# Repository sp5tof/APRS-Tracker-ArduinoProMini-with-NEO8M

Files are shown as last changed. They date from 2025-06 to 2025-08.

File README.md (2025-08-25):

# APRS Tracker/Decoder for Baofeng based on ArduinoProMini, ESP32 & NEO8M GPS receiver module
This project is based on:

- Billy's project : https://github.com/billygr/arduino-aprs-tracker  - more informations: https://www.billy.gr/arduino-aprs-tracker/ &
- ESP32 iGate project https://github.com/nakhonthai/ESP32APRS_Audio

It consists of two independent uC: Arduino Pro-Mini for TNC transmition and ESP-Wroom32 with OLED board for visual decoding incoming APRS frames.
This is becouse I wasn't able to force Atmega328p with Arduino bootloader to decode any AX.25 frames using the another decoder idea :
https://github.com/chokelive/aprs_tnc .
From the other hand, ESP32 iGate standalone project doesn't seem to support the NEO8M GPS receiver. 
That's why I decided to use hybrid solution consists of two independent microprocessors.

Attached Eagle STL/BRD PCB allows to put them all together.

Baofeng is used as transceiver for this project and connected with two embedded mini-jacks sockets for TX/RX datas & PTT triggering.

I changed few things related to genuine project(Arduino Pro-Mini part):
- support for NEO8M GPS module (TinyGPS library has to be changed, I added the modified library here)
- small change made on original Billy's arduino code related to GPS module
- I used Arduino Pro mini in 5V version and adopted author's code to use this one
- added additional button for changing the APRS symbol(pressing it during the powering ON the device would change the symbol from "car" to "walking man")

I added external speaker with embedded preamp to the circuit as you can see on the schema. Baofeng turns off it's internal speaker when the mini-jack is plugged in. The idea behind the external speaker is about possibility of listening incoming APRS frames. Unfortunatelly, two audio receivers on the DAC output of esp32 makes overriding the audio line. That's why I had to add the audio splitter based on TL072.
  
Cable required for connecting the Baofeng with the device you have to make on your own. I wasn't able to find fully compatible 4-pins (MIC, SPK, PTT, GND) cable with any well-known online stores. However, you can try to order the baofeng audio cable from chinese online store, but the additional changes will have to be made according the the attached schema and pinout available in the net, f. ex : https://www.miklor.com/COM/images/dualplug.jpg .

For Arduino part, please compile and upload attached .ino code to the Arduino Pro-Mini.
Make necessary changes within the code according to your preferences (callsing, comment etc.).

In case of ESP32 part, please follow the manual within the link mentioned above on the nakhonthai github page. 
You have to flash the ESP board. You don't need to configure anything within the ESP32. 
Decoding functionality which is used in this project, works by default without any additional configurations steps to be performed.
I used the ESP-WROOM32 board with embedded OLED display, which works correctly(with version 13a of firmware version, added to this library. However, please use the newest available release on the nakhonthai github page, which should works correctly).

schema_image

PCB_image
mounted_schema

 Kuba/SP5TOF

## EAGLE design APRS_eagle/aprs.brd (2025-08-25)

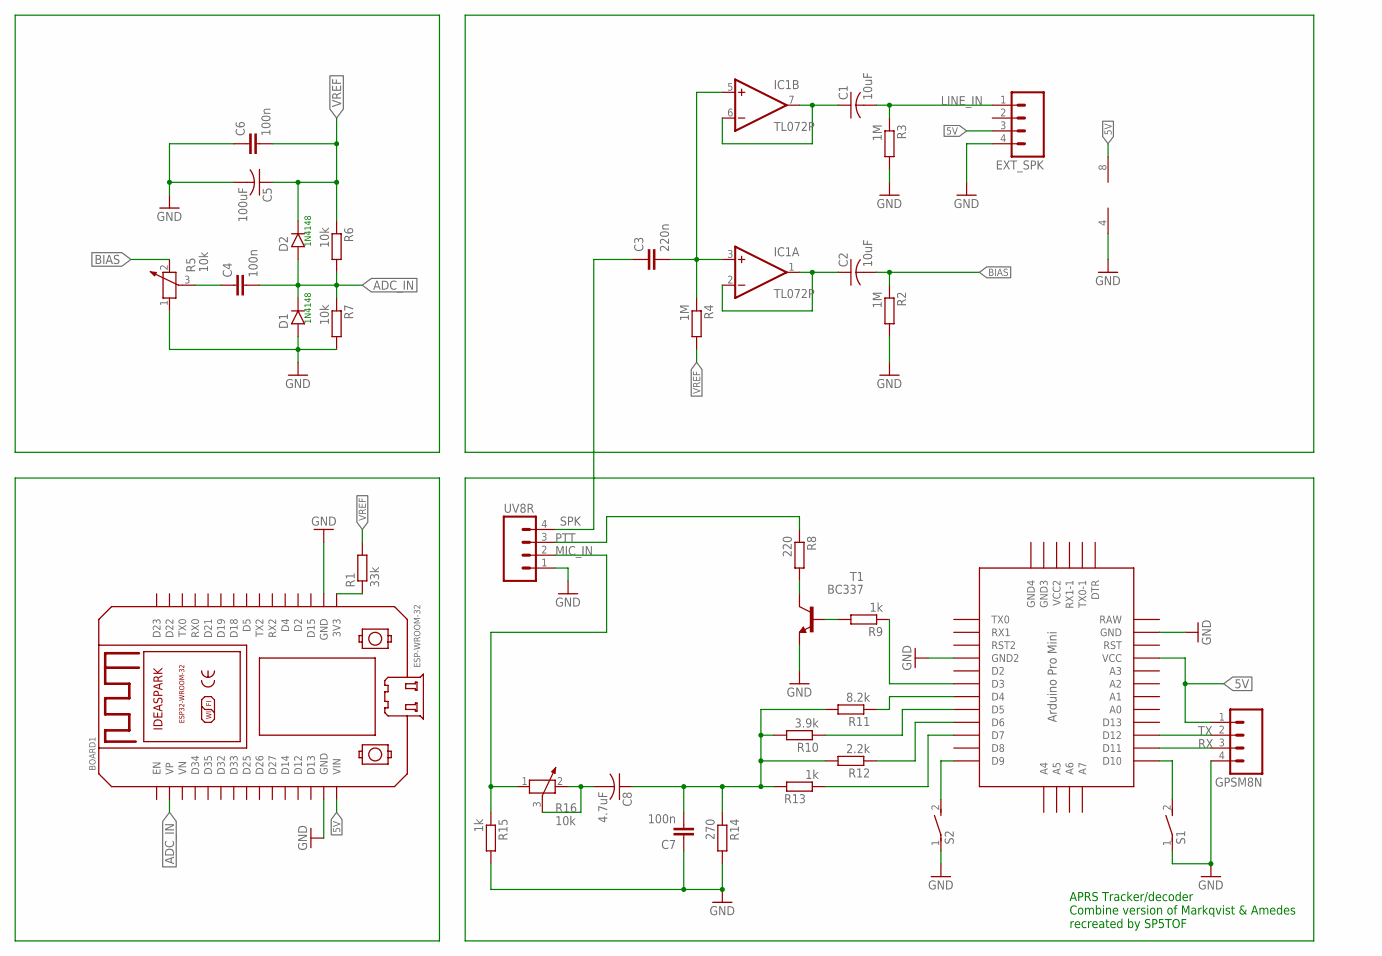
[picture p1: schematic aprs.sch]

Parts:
BOARD1: ESP32DEVKITV1; ESP32-DEVKITV1
C1, C2: 10uF; C050-035X075
C3: 220n; C025-025X050
C4, C6, C7: 100n; C025-025X050
C5: 100uF; C050-035X075
C8: 4.7uF; C050-035X075
D1, D2: 1N4148-3; DO35-3
EXT_SPK: M04; 04P
GPSM8N: M04; 04P
IC1: TL072P; DIL08
R1: 33k; 0207/7
R2, R3, R4: 1M; 0207/7
R5, R16: 10k; PT-10S
R6, R7: 10k; 0207/7
R8: 220; 0207/7
R9, R13, R15: 1k; 0207/7
R10: 3.9k; 0207/7
R11: 8.2k; 0207/7
R12: 2.2k; 0207/7
R14: 270; 0207/7
S1, S2: DS01E; DS-01
T1: BC337; TO92
U$1: PRO-MINI
UV8R: M04; 04P

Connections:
5V: BOARD1.VIN, EXT_SPK.3, GPSM8N.1, IC1.8 (V+), U$1.VCC
ADC_IN: BOARD1.VP, C4.2, D1.C, D2.A, R6.2, R7.1
BIAS: C2.2, R2.1, R5.2
GND: BOARD1.GND, BOARD1.GND@1 (GND), C5.2, C6.1, C7.1, D1.A, EXT_SPK.4, GPSM8N.4, IC1.4 (V-), R2.2, R3.2, R5.1, R7.2, R14.2, R15.2, S1.1, S2.1, T1.1 (E), U$1.GND, U$1.GND1 (GND2), UV8R.1
LINE_IN: C1.2, EXT_SPK.1, R3.1
MIC_IN: R15.1, R16.1, UV8R.2
unnamed: BOARD1.3V3, R1.1
unnamed: C1.1, IC1.6 (-IN), IC1.7 (OUT)
unnamed: C2.1, IC1.1 (OUT), IC1.2 (-IN)
unnamed: S2.2, U$1.D9
unnamed: C3.2, IC1.3 (+IN), IC1.5 (+IN), R4.1
unnamed: C4.1, R5.3
unnamed: S1.2, U$1.D10
unnamed: R9.1, U$1.D3
unnamed: R9.2, T1.2 (B)
unnamed: R8.2, T1.3 (C)
unnamed: R11.1, U$1.D4
unnamed: R10.1, U$1.D5
unnamed: R12.1, U$1.D6
unnamed: R13.1, U$1.D7
unnamed: C7.2, C8.1, R10.2, R11.2, R12.2, R13.2, R14.1
unnamed: C8.2, R16.2, R16.3
PTT: R8.1, UV8R.3
RAW: U$1.RAW
RX: GPSM8N.3, U$1.D11
SPK: C3.1, UV8R.4
TX: GPSM8N.2, U$1.D12
VREF: C5.1, C6.2, D2.C, R1.2, R4.2, R6.1

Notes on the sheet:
1N4148
APRS Tracker/decoder Combine version of Markqvist & Amedes recreated by SP5TOF

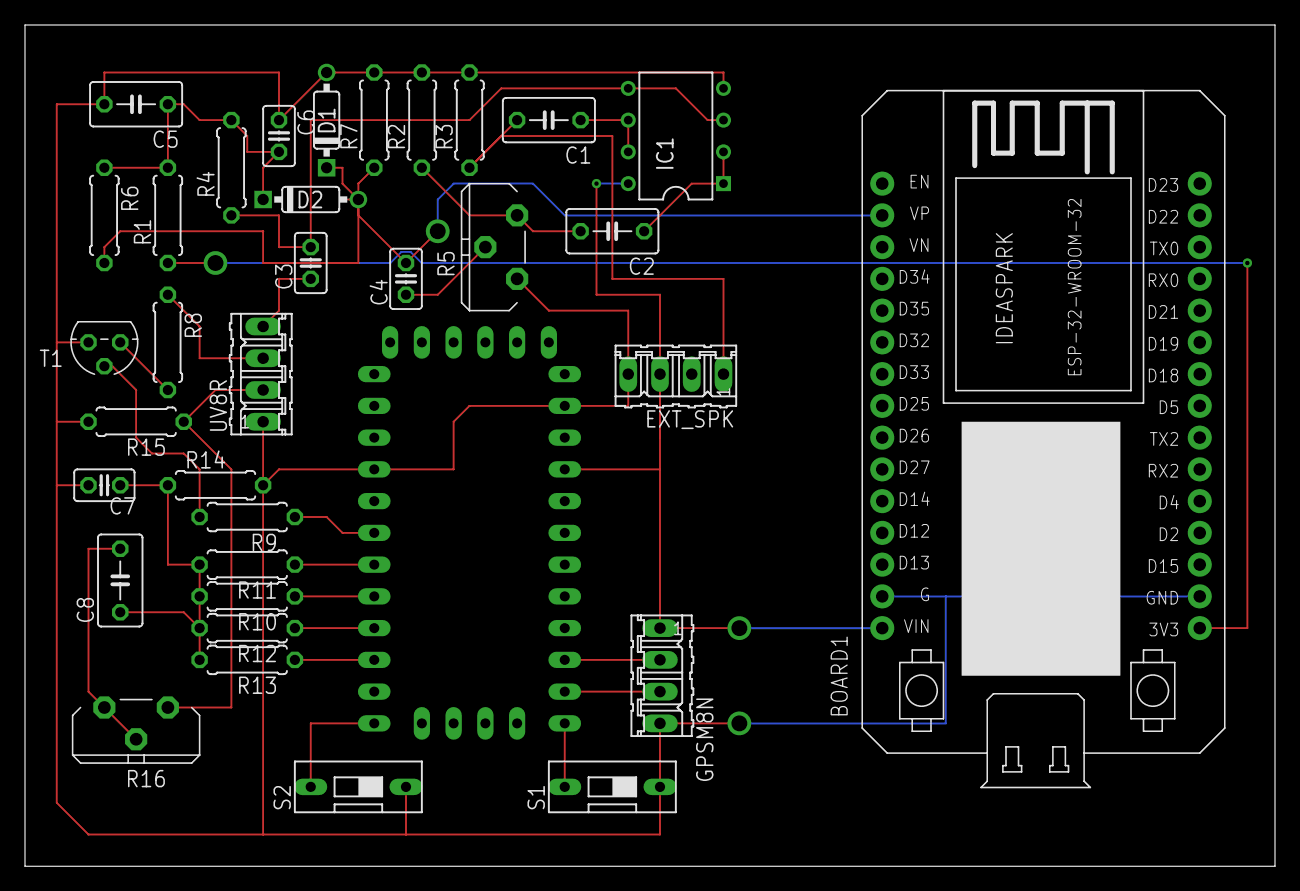
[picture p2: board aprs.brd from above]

Board: 2 copper layers, 100.0 x 67.3 mm, 35 parts (0 on the bottom side), 27 nets.

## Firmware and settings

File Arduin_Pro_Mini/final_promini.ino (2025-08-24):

/***
 * Arduino APRS Tracker (aat) with Arduino Pro Mini 3.3V/8 MHz
 * Install the following libraries through Arduino Library Manager
 * - TinyGPS by Mikal Hart
 * -
 * - Modified by Jakub/SP5TOF for additional button of symbol changing & NEO8M GPS receiver support 
 ***/

#include <SoftwareSerial.h>
#include <TinyGPS.h>
#include <LibAPRS.h>

// Enable this define NEO6M if you are constantly getting wrong data,
// the ADC ISR triggers during SoftwareSerial so we miss data coming from GPS
// (for some reason only on this type of GPS and only when running on 9600 bps)
#define NEO6M

// Manual update button
#define BUTTON_PIN 10
// button for select the symbol between the car and walking man
#define BUTTON_PIN2 9

// GPS SoftwareSerial
// Shares pins with (MISO 12/ MOSI 11) used for SPI
#define GPS_RX_PIN 11
#define GPS_TX_PIN 12
TinyGPS gps;
SoftwareSerial GPSSerial(GPS_RX_PIN, GPS_TX_PIN);

// LibAPRS
#define OPEN_SQUELCH false
#define ADC_REFERENCE REF_5V

// PPT_PIN is defined on libAPRS/device.h
//#define PPT_PIN 3

// GPS_FIX_LED A3/D17
#define GPS_FIX_LED A3

// APRS settings
char APRS_CALLSIGN[] = "SP5TOF";
const int APRS_SSID = 5;



// SmartBeaconing(tm) Setting  http://www.hamhud.net/hh2/smartbeacon.html implementation by LU5EFN

#define LOW_SPEED 5 // [km/h]
#define HIGH_SPEED 90

#define SLOW_RATE 1750 // [seg]
#define FAST_BEACON_RATE  175

#define TURN_MIN  30
#define TURN_SLOPE  240
#define MIN_TURN_TIME 20

//long instead of float for latitude and longitude
long lat = 0;
long lon = 0;

int speed_kt = 0;
int currentcourse = 0;
int ialtitude_feet = 0;

unsigned long lastTX = 0, tx_interval = 0;
int previouscourse = 0, turn_threshold = 0, courseDelta = 0;

bool newData = false;
// buffer for conversions
#define CONV_BUF_SIZE 16
static char conv_buf[CONV_BUF_SIZE];

/*****************************************************************************************/
void setup()
{
  Serial.begin(115200);
  GPSSerial.begin(9600);

#ifdef NEO6M
  GPSSerial.print("$PUBX,41,1,0007,0003,4800,0*13\r\n");
  GPSSerial.begin(4800);
  GPSSerial.flush();
#endif

  // Reduce NMEA messages
  disableGPGLL();
  // pin for manual update
  pinMode(BUTTON_PIN, INPUT_PULLUP);
   //symbol select 
  pinMode (BUTTON_PIN2, INPUT_PULLUP);
char APRS_SYMBOL = '>';
char APRS_SYMBOL2 = '[';

  pinMode(GPS_FIX_LED,OUTPUT);

  Serial.println(F("Arduino APRS Tracker"));

  APRS_init(ADC_REFERENCE, OPEN_SQUELCH);
  APRS_setCallsign(APRS_CALLSIGN,APRS_SSID);

if (digitalRead(BUTTON_PIN2)==LOW)
    {
      Serial.println(F("Symbol changed to the walking man"));
       APRS_setSymbol(APRS_SYMBOL2);
    }
    else
    {
      APRS_setSymbol(APRS_SYMBOL);
    }

  Serial.print(F("Callsign:     ")); Serial.print(APRS_CALLSIGN); Serial.print(F("-")); Serial.println(APRS_SSID);
  Serial.print(F("Free RAM:     ")); Serial.println(freeMemory());
  Serial.println(F("Date       Time     Latitude  Longitude  Course Speed APRS Lat/Lon       Altitude   Course current/Delta/turn_threshold"));
  Serial.println(F("                    (deg)     (deg)      (deg)  (Km/h)DDMM.mmN/DDDMM.mmW (m/ft)                "));
  Serial.println(F("-----------------------------------------------------------------------------------------------"));
}

static void smartdelay(unsigned long ms)
{
  unsigned long start = millis();
  do
  {
    while (GPSSerial.available())
      {
        if (gps.encode(GPSSerial.read())) newData = true;

      }
  } while (millis() - start < ms);
}

static void print_int(unsigned long val, unsigned long invalid, int len)
{
  char sz[32];
  if (val == invalid)
    strcpy(sz, "*******");
  else
    sprintf(sz, "%ld", val);
  sz[len] = 0;
  for (int i=strlen(sz); i<len; ++i)
    sz[i] = ' ';
  if (len > 0)
    sz[len-1] = ' ';
  Serial.print(sz);
  smartdelay(0);
}

static void print_float(float val, float invalid, int len, int prec)
{
  if (val == invalid)
  {
    while (len-- > 1)
      Serial.print('*');
    Serial.print(' ');
  }
  else
  {
    Serial.print(val, prec);
    int vi = abs((int)val);
    int flen = prec + (val < 0.0 ? 2 : 1); // . and -
    flen += vi >= 1000 ? 4 : vi >= 100 ? 3 : vi >= 10 ? 2 : 1;
    for (int i=flen; i<len; ++i)
      Serial.print(' ');
  }
  smartdelay(0);
}

static void print_date(TinyGPS &gps)
{
  int year;
  byte month, day, hour, minute, second, hundredths;
  unsigned long age;
  gps.crack_datetime(&year, &month, &day, &hour, &minute, &second, &hundredths, &age);
  if (age == TinyGPS::GPS_INVALID_AGE)
    Serial.print(F("********** ******** "));
  else
  {
    char sz[32];
    sprintf(sz, "%02d/%02d/%02d %02d:%02d:%02d ",
        month, day, year, hour, minute, second);
    Serial.print(sz);
  }
  smartdelay(0);
}
/*****************************************************************************************/
void loop()
{
  float flat, flon;

  unsigned long age=0;

  float faltitude_meters=0, fkmph=0;

  // Process GPS data every second (or so)
  smartdelay(1000);
  gps.get_position(&lat, &lon, &age);

  while (age == TinyGPS::GPS_INVALID_AGE)
  {
    // It is not an ideal check but provides a good indication, could be no fix/GPS is not connected/GPS is sending garbage
    Serial.println(F("No fix detected"));
    smartdelay(1000);
    gps.get_position(&lat, &lon, &age);
  }

  if (newData && lat !=0)
  {
    // Parse twice the location with both float and long. Using float helps to paste it directly to google maps for troubleshooting
    gps.get_position(&lat, &lon, &age);
    gps.f_get_position(&flat, &flon, &age);

    // TinyGPS reports TinyGPS::GPS_INVALID_F_ALTITUDE = 1000000.0 for invalid altitude
    faltitude_meters = gps.f_altitude(); // +/- altitude in meters

    // Quick fix to ignore wrong data in calculations
    if (int (faltitude_meters) > 30000) faltitude_meters =0;
    ialtitude_feet = int(faltitude_meters*3.281);  // integer value of altitude in feet

    fkmph = gps.f_speed_kmph(); // speed in km/h

    // Quick fix to ignore wrong data in calculations
    if (int (fkmph) > 300) fkmph = 0;

    speed_kt = (int) gps.f_speed_knots(); // speed in knots for APRS

    // TinyGPS reports TinyGPS::GPS_INVALID_F_ANGLE = 1000.0 for invalid course
    currentcourse = (int) gps.f_course();

    // Quick fix to ignore wrong data in calculations
    if (currentcourse > 360 || currentcourse < 0) currentcourse=0;

    // Calculate difference of course to smartbeacon
    courseDelta = (int) ( previouscourse - currentcourse );
    courseDelta = abs (courseDelta);
    if (courseDelta > 180) {
      courseDelta = courseDelta - 360;
    }
    courseDelta = abs (courseDelta) ;

    digitalWrite(GPS_FIX_LED, !digitalRead(GPS_FIX_LED)); // Toggle the GPS_FIX_LED on/off

    print_date(gps);
    print_float(flat, TinyGPS::GPS_INVALID_F_ANGLE, 10, 6);
    print_float(flon, TinyGPS::GPS_INVALID_F_ANGLE, 11, 6);
    print_float(gps.f_course(), TinyGPS::GPS_INVALID_F_ANGLE, 7, 2);
    print_float(fkmph, TinyGPS::GPS_INVALID_F_SPEED, 6, 2);
    Serial.print(deg_to_nmea(lat, true));Serial.print(F("/"));Serial.print(deg_to_nmea(lon, false));
    Serial.print(F(" ")); Serial.print(faltitude_meters);Serial.print(F("/"));Serial.print(ialtitude_feet);

    // Based on HamHUB Smart Beaconing(tm) algorithm
    if ( fkmph < LOW_SPEED ) {
      tx_interval = SLOW_RATE *1000L;
    }
    else if ( fkmph > HIGH_SPEED) {
      tx_interval = FAST_BEACON_RATE  *1000L;
    }
    else {
    // Interval inbetween low and high speed
      tx_interval = ((FAST_BEACON_RATE * HIGH_SPEED) / fkmph ) *1000L ;
    }

    turn_threshold = TURN_MIN + TURN_SLOPE / fkmph;

    Serial.print(F(" "));Serial.print(currentcourse);Serial.print(F(" "));Serial.print(courseDelta);
    Serial.print(F(" "));Serial.println(turn_threshold);

    if (courseDelta > turn_threshold ){
      if ( millis() - lastTX > MIN_TURN_TIME *1000L){
        Serial.println(F("DEBUG: APRS UPDATE because of millis() - lastTX > MIN_TURN_TIME *1000L"));
        locationUpdate();
        lastTX = millis();
      }
    }

    previouscourse = currentcourse;
    // tx_internal with default values 1750000 milliseconds/1750 seconds/29.16 minutes
    if ( millis() - lastTX > tx_interval) {
      Serial.println(F("DEBUG: APRS UPDATE because of millis() - lastTX > tx_interval"));
      locationUpdate();
      lastTX = millis();
    }

    if (digitalRead(BUTTON_PIN)==0)
    {
      while(digitalRead(BUTTON_PIN)==0) {}; //debounce
      Serial.println(F("MANUAL UPDATE"));
      locationUpdate();
    }
  }
  newData = false;
}

/*****************************************************************************************/
void aprs_msg_callback(struct AX25Msg *msg) {
}

/*****************************************************************************************/
void locationUpdate() {
//Altitude in Comment Text — The comment may contain an altitude value,
//in the form /A=aaaaaa, where aaaaaa is the altitude in feet. For example:
//A=001234. The altitude may appear anywhere in the comment.
//Source: APRS protocol
//Which means /A=000XXXArduino APRS Tracker (29 characters)

char comment []= "SP5TOF w trasie";
  
  char temp[8];
  char APRS_comment [32]="/A=";

  // Convert altitude in string and pad left
  sprintf(temp, "%06d", ialtitude_feet);
  strcat(APRS_comment,temp);
  strcat(APRS_comment,comment);
  //Serial.println(APRS_comment);

  APRS_setLat((char*)deg_to_nmea(lat, true));
  APRS_setLon((char*)deg_to_nmea(lon, false));

  APRS_setSpeed(speed_kt);
  APRS_setCourse(currentcourse);

  // turn off SoftSerial to stop interrupting tx
  GPSSerial.end();

  // TX
  APRS_sendLoc(APRS_comment, strlen(APRS_comment));

  // read TX LED pin and wait till TX has finished. LibAPRS has TX_LED defined on (PB5), i use LED_BUILTIN on my version as TX_LED
  while(digitalRead(LED_BUILTIN));

  // start SoftSerial again
#ifdef NEO6M
   GPSSerial.begin(4800);
#else
   GPSSerial.begin(9600);
#endif
}

/*****************************************************************************************/
/*
**  Convert degrees in long format to APRS string format
**  DDMM.hhN for latitude and DDDMM.hhW for longitude
**  D is degrees, M is minutes and h is hundredths of minutes.
**  http://www.aprs.net/vm/DOS/PROTOCOL.HTM
*/
char* deg_to_nmea(long deg, boolean is_lat) {
  bool is_negative=0;
  if (deg < 0) is_negative=1;

  // Use the absolute number for calculation and update the buffer at the end
  deg = labs(deg);

  unsigned long b = (deg % 1000000UL) * 60UL;
  unsigned long a = (deg / 1000000UL) * 100UL + b / 1000000UL;
  b = (b % 1000000UL) / 10000UL;

  conv_buf[0] = '0';
  // in case latitude is a 3 digit number (degrees in long format)
  if( a > 9999) {
    snprintf(conv_buf , 6, "%04lu", a);
  } else {
    snprintf(conv_buf + 1, 5, "%04lu", a);
  }

  conv_buf[5] = '.';
  snprintf(conv_buf + 6, 3, "%02lu", b);
  conv_buf[9] = '\0';
  if (is_lat) {
    if (is_negative) {conv_buf[8]='S';}
    else conv_buf[8]='N';
    return conv_buf+1;
    // conv_buf +1 because we want to omit the leading zero
    }
  else {
    if (is_negative) {conv_buf[8]='W';}
    else conv_buf[8]='E';
    return conv_buf;
    }
}

void disableGPGLL()
{
  const char *msg = "PUBX,40,GLL,0,0,0,0,0";

  // find checksum
  int checksum = 0;
  for (int i = 0; msg[i]; i++)
    checksum ^= (unsigned char)msg[i];

  // convert and create checksum HEX string
  char checkTmp[8];
  snprintf(checkTmp, sizeof(checkTmp)-1, "*%.2X", checksum);

  // send to module
  GPSSerial.print("$");
  GPSSerial.print(msg);
  GPSSerial.println(checkTmp);
  GPSSerial.flush();
}

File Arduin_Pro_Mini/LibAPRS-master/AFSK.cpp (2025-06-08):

#include <string.h>
#include "AFSK.h"
#include "Arduino.h"

extern unsigned long custom_preamble;
extern unsigned long custom_tail;
extern int LibAPRS_vref;
extern bool LibAPRS_open_squelch;

bool hw_afsk_dac_isr = false;
bool hw_5v_ref = false;
Afsk *AFSK_modem;


// Forward declerations
int afsk_getchar(void);
void afsk_putchar(char c);

void AFSK_hw_refDetect(void) {
    // This is manual for now
    if (LibAPRS_vref == REF_5V) {
        hw_5v_ref = true;
    } else {
        hw_5v_ref = false;
    }
}

void AFSK_hw_init(void) {
    // Set up ADC

    AFSK_hw_refDetect();

    TCCR1A = 0;                                    
    TCCR1B = _BV(CS10) | _BV(WGM13) | _BV(WGM12);
    ICR1 = (((CPU_FREQ+FREQUENCY_CORRECTION)) / 9600) - 1;

    if (hw_5v_ref) {
        ADMUX = _BV(REFS0) | 0;
    } else {

// Arduino Pro Mini 5V 16 MHz or Arduino Pro Mini 3V3 8 MHz have hardcoded the AREF to VCC
#ifdef ARDUINO_AVR_PRO
        ADMUX = _BV(REFS0) | 0;
#else
        ADMUX = 0;
#endif
    }

    ADC_DDR  &= ~_BV(ADC_PIN);
    ADC_PORT &= ~_BV(ADC_PIN);
    DIDR0 |= _BV(ADC_PIN);
    ADCSRB =    _BV(ADTS2) |
                _BV(ADTS1) |
                _BV(ADTS0);  
    ADCSRA =    _BV(ADEN) |
                _BV(ADSC) |
                _BV(ADATE)|
                _BV(ADIE) |
                _BV(ADPS2);

    AFSK_DAC_INIT();
    LED_TX_INIT();
    LED_RX_INIT();
}

void AFSK_init(Afsk *afsk) {
    // Allocate modem struct memory
    memset(afsk, 0, sizeof(*afsk));
    AFSK_modem = afsk;
    // Set phase increment
    afsk->phaseInc = MARK_INC;
    // Initialise FIFO buffers
    fifo_init(&afsk->delayFifo, (uint8_t *)afsk->delayBuf, sizeof(afsk->delayBuf));
    fifo_init(&afsk->rxFifo, afsk->rxBuf, sizeof(afsk->rxBuf));
    fifo_init(&afsk->txFifo, afsk->txBuf, sizeof(afsk->txBuf));

    // Fill delay FIFO with zeroes
    for (int i = 0; i<SAMPLESPERBIT / 2; i++) {
        fifo_push(&afsk->delayFifo, 0);
    }

    AFSK_hw_init();

}

static void AFSK_txStart(Afsk *afsk) {
    if (!afsk->sending) {
        afsk->phaseInc = MARK_INC;
        afsk->phaseAcc = 0;
        afsk->bitstuffCount = 0;
        afsk->sending = true;
        LED_TX_ON();
        afsk->preambleLength = DIV_ROUND(custom_preamble * BITRATE, 8000);
        AFSK_DAC_IRQ_START();
    }
    ATOMIC_BLOCK(ATOMIC_RESTORESTATE) {
      afsk->tailLength = DIV_ROUND(custom_tail * BITRATE, 8000);
    }
}

void afsk_putchar(char c) {
    AFSK_txStart(AFSK_modem);
    while(fifo_isfull_locked(&AFSK_modem->txFifo)) { /* Wait */ }
    fifo_push_locked(&AFSK_modem->txFifo, c);
}

int afsk_getchar(void) {
    if (fifo_isempty_locked(&AFSK_modem->rxFifo)) {
        return EOF;
    } else {
        return fifo_pop_locked(&AFSK_modem->rxFifo);
    }
}

void AFSK_transmit(char *buffer, size_t size) {
    fifo_flush(&AFSK_modem->txFifo);
    int i = 0;
    while (size--) {
        afsk_putchar(buffer[i++]);
    }
}

uint8_t AFSK_dac_isr(Afsk *afsk) {
    if (afsk->sampleIndex == 0) {
        if (afsk->txBit == 0) {
            if (fifo_isempty(&afsk->txFifo) && afsk->tailLength == 0) {
                AFSK_DAC_IRQ_STOP();
                afsk->sending = false;
                LED_TX_OFF();
                return 0;
            } else {
                if (!afsk->bitStuff) afsk->bitstuffCount = 0;
                afsk->bitStuff = true;
                if (afsk->preambleLength == 0) {
                    if (fifo_isempty(&afsk->txFifo)) {
                        afsk->tailLength--;
                        afsk->currentOutputByte = HDLC_FLAG;
                    } else {
                        afsk->currentOutputByte = fifo_pop(&afsk->txFifo);
                    }
                } else {
                    afsk->preambleLength--;
                    afsk->currentOutputByte = HDLC_FLAG;
                }
                if (afsk->currentOutputByte == AX25_ESC) {
                    if (fifo_isempty(&afsk->txFifo)) {
                        AFSK_DAC_IRQ_STOP();
                        afsk->sending = false;
                        LED_TX_OFF();
                        return 0;
                    } else {
                        afsk->currentOutputByte = fifo_pop(&afsk->txFifo);
                    }
                } else if (afsk->currentOutputByte == HDLC_FLAG || afsk->currentOutputByte == HDLC_RESET) {
                    afsk->bitStuff = false;
                }
            }
            afsk->txBit = 0x01;
        }

        if (afsk->bitStuff && afsk->bitstuffCount >= BIT_STUFF_LEN) {
            afsk->bitstuffCount = 0;
            afsk->phaseInc = SWITCH_TONE(afsk->phaseInc);
        } else {
            if (afsk->currentOutputByte & afsk->txBit) {
                afsk->bitstuffCount++;
            } else {
                afsk->bitstuffCount = 0;
                afsk->phaseInc = SWITCH_TONE(afsk->phaseInc);
            }
            afsk->txBit <<= 1;
        }

        afsk->sampleIndex = SAMPLESPERBIT;
    }

    afsk->phaseAcc += afsk->phaseInc;
    afsk->phaseAcc %= SIN_LEN;
    afsk->sampleIndex--;

    return sinSample(afsk->phaseAcc);
}
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
